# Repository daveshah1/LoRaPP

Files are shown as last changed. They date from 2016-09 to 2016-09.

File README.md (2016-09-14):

# LoRa++

Small, flexible LoRa module designed for HAB use as well as general 
long distance comms.

Features:
 * SX1276 LoRa transceiver
 * Same PCB can be used for 434MHz, 868MHz and probably other 
frequencies (different components required)
 * MMZ09312 PA for >27dBm output power (for 869.525MHz use in EU). 
Optional, can be bypassed with 0 ohm resistors if not needed.
 * SAW filter and MAAL-010704 LNA (also optional) in receive path 

Note: this is still in the fairly early design phase; the PCB design has 
not yet been checked or built.

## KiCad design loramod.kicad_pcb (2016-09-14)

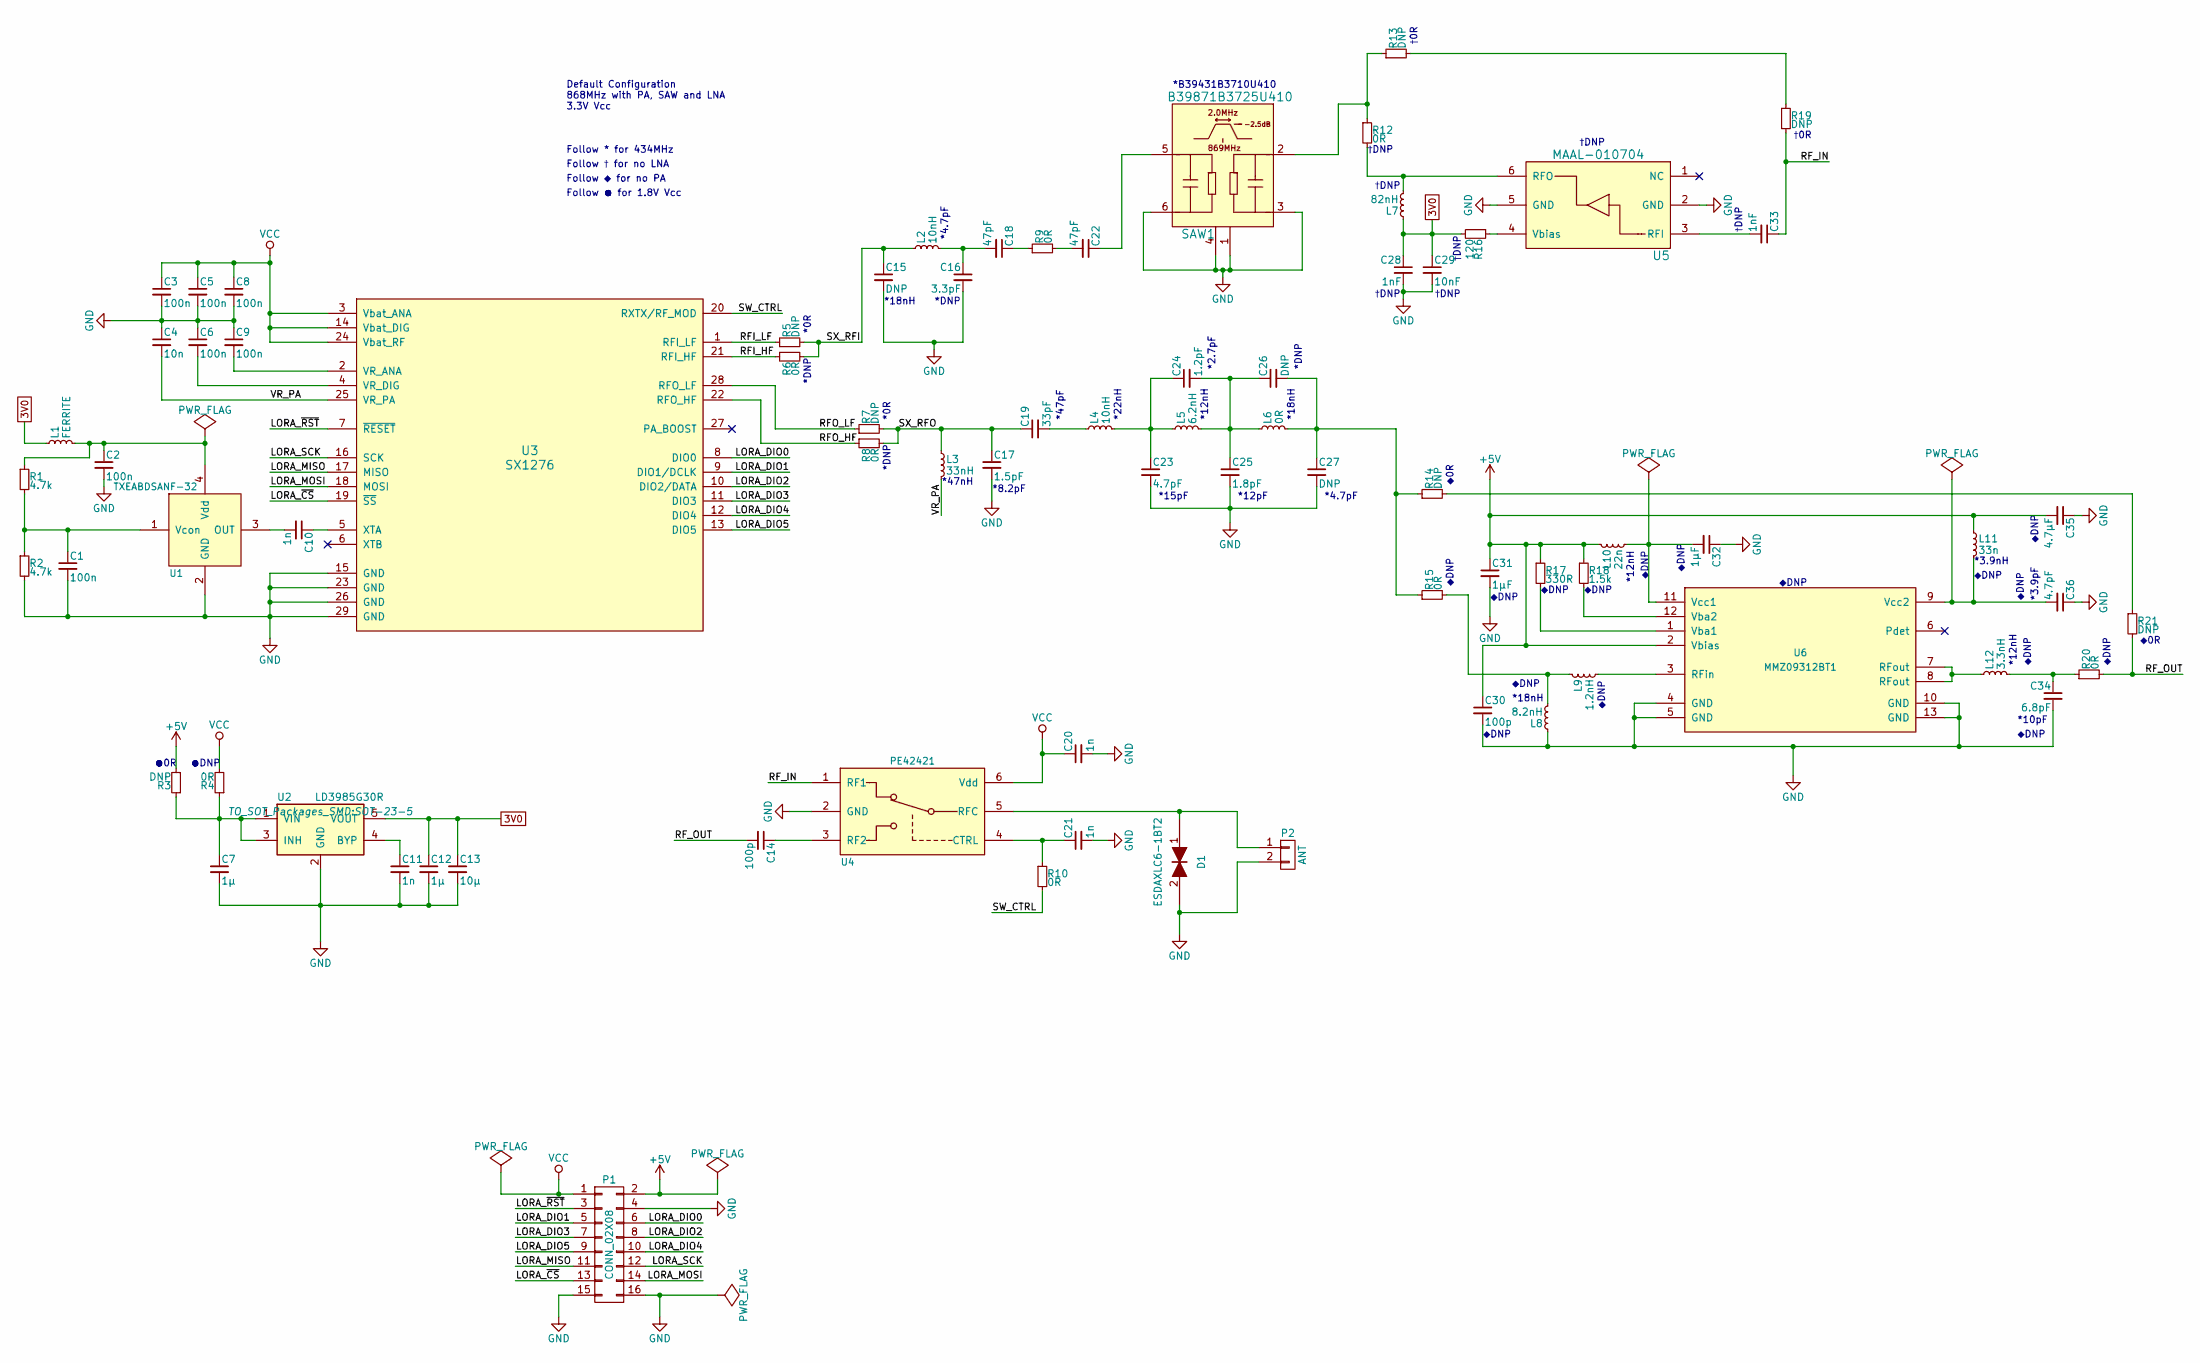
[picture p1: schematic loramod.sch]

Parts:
C1, C2, C3, C5, C6, C8, C9: 100n; C_0402
C4: 10n; C_0402
C7: 1µ; C_0603_HandSoldering
C10, C11, C20, C21: 1n; C_0402
C12: 1µ; C_0603
C13: 10µ; C_0805
C14, C30: 100p; C_0402
C15, C26, C27: DNP; C_0402
C16: 3.3pF; C_0402
C17: 1.5pF; C_0402
C18, C22: 47pF; C_0402
C19: 33pF; C_0402
C23, C36: 4.7pF; C_0402
C24: 1.2pF; C_0402
C25: 1.8pF; C_0402
C28, C33: 1nF; C_0402
C29: 10nF; C_0402
C31, C32: 1µF; C_0402
C34: 6.8pF; C_0402
C35: 4.7µF; C_0805
D1: ESDAXLC6-1BT2; C_0402
L1: FERRITE; R_0402
L2, L4: 10nH; R_0402
L3: 33nH; R_0402
L5: 6.2nH; R_0402
L6: 0R; R_0402
L7: 82nH; R_0402
L8: 8.2nH; R_0402
L9: 1.2nH; R_0402
L10: 22n; R_0402
L11: 33n; R_0402
L12: 3.3nH; R_0402
P1: CONN_02X08; Pin_Header_Straight_2x08_Pitch2.00mm
P2: ANT; RFcon
R1, R2: 4.7k; R_0402
R3, R5, R7, R13, R14, R19, R21: DNP; R_0402
R4, R6, R8, R9, R10, R12, R15, R20: 0R; R_0402
R16: 120; R_0402
R17: 330R; R_0402
R18: 1.5k; R_0402
SAW1: B39871B3725U410; SAW-DCC6C
U1: TXEABDSANF-32; TCXO-WT325
U2: LD3985G30R; SOT-23-5
U3: SX1276; QFN-28-1EP_6x6mm_Pitch0.65mm
U4: PE42421; SC-70-6_Handsoldering
U5: MAAL-010704; SC-70-6_Handsoldering
U6: MMZ09312BT1; QFN-12-1EP_3x3mm_Pitch0.5mm

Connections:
3V0: C12.1, C13.1, C28.1, C29.1, L1.1, L7.1, R16.2, U2.5 (VOUT)
+5V: C30.1, C31.1, C35.2, L10.1, L11.1, P1.2, R3.2, R17.1, R18.1, U6.2 (Vbias)
/LORA_DIO0: P1.6, U3.8 (DIO0)
/LORA_DIO1: P1.5, U3.9 (DIO1/DCLK)
/LORA_DIO2: P1.8, U3.10 (DIO2/DATA)
/LORA_DIO3: P1.7, U3.11 (DIO3)
/LORA_DIO4: P1.10, U3.12 (DIO4)
/LORA_DIO5: P1.9, U3.13 (DIO5)
/LORA_MISO: P1.11, U3.17 (MISO)
/LORA_MOSI: P1.14, U3.18 (MOSI)
/LORA_SCK: P1.12, U3.16 (SCK)
/LORA_~CS: P1.13, U3.19 (~SS)
/LORA_~RST: P1.3, U3.7 (~RESET)
/RFI_HF: R6.1, U3.21 (RFI_HF)
/RFI_LF: R5.1, U3.1 (RFI_LF)
/RFO_HF: R8.1, U3.22 (RFO_HF)
/RFO_LF: R7.1, U3.28 (RFO_LF)
/RF_IN: C33.1, R19.2, U4.1 (RF1)
/RF_OUT: C14.2, R20.2, R21.2
/SW_CTRL: R10.2, U3.20 (RXTX/RF_MOD)
/SX_RFI: C15.1, L2.1, R5.2, R6.2
/SX_RFO: C17.1, C19.1, L3.1, R7.2, R8.2
/VR_PA: C4.2, L3.2, U3.25 (VR_PA)
GND: C1.2, C2.2, C3.2, C4.1, C5.2, C6.1, C7.2, C8.2, C9.1, C11.2, C12.2, C13.2, C15.2, C16.2, C17.2, C20.2, C21.2, C23.2, C25.2, C27.2, C28.2, C29.2, C30.2, C31.2, C32.1, C34.2, C35.1, C36.1, D1.2, L8.1, P1.4, P1.15, P1.16, P2.2, R2.2, SAW1.1 (GND), SAW1.3 (GND), SAW1.4 (GND), SAW1.6 (GND), U1.2 (GND), U2.2 (GND), U3.15 (GND), U3.23 (GND), U3.26 (GND), U3.29 (GND), U4.2 (GND), U5.2 (GND), U5.5 (GND), U6.4 (GND), U6.5 (GND), U6.10 (GND), U6.13 (GND)
unnamed: C1.1, R1.2, R2.1, U1.1 (Vcon)
unnamed: C2.1, L1.2, R1.1, U1.4 (Vdd)
unnamed: C6.2, U3.4 (VR_DIG)
unnamed: C7.1, R3.1, R4.1, U2.1 (VIN), U2.3 (INH)
unnamed: C9.2, U3.2 (VR_ANA)
unnamed: C10.1, U3.5 (XTA)
unnamed: C10.2, U1.3 (OUT)
unnamed: C11.1, U2.4 (BYP)
unnamed: C14.1, U4.3 (RF2)
unnamed: C16.1, C18.2, L2.2
unnamed: C18.1, R9.1
unnamed: C19.2, L4.1
unnamed: C21.1, R10.1, U4.4 (CTRL)
unnamed: C22.1, SAW1.5 (OUT)
unnamed: C22.2, R9.2
unnamed: C23.1, C24.1, L4.2, L5.1
unnamed: C24.2, C25.1, C26.1, L5.2, L6.1
unnamed: C26.2, C27.1, L6.2, R14.1, R15.1
unnamed: C32.2, L10.2, U6.11 (Vcc1)
unnamed: C33.2, U5.3 (RFI)
unnamed: C34.1, L12.2, R20.1
unnamed: C36.2, L11.2, U6.9 (Vcc2)
unnamed: D1.1, P2.1, U4.5 (RFC)
unnamed: L7.2, R12.2, U5.6 (RFO)
unnamed: L8.2, L9.1, R15.2
unnamed: L9.2, U6.3 (RFin)
unnamed: L12.1, U6.7 (RFout), U6.8 (RFout)
unnamed: R12.1, R13.1, SAW1.2 (IN)
unnamed: R13.2, R19.1
unnamed: R14.2, R21.1
unnamed: R16.1, U5.4 (Vbias)
unnamed: R17.2, U6.1 (Vba1)
unnamed: R18.2, U6.12 (Vba2)
VCC: C3.1, C5.1, C8.1, C20.1, P1.1, R4.2, U3.3 (Vbat_ANA), U3.14 (Vbat_DIG), U3.24 (Vbat_RF), U4.6 (Vdd)

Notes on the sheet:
*18nH
*DNP
*4.7pF
*DNP
*0R
*B39431B3710U410
Default Configuration 868MHz with PA, SAW and LNA 3.3V Vcc
Follow * for 434MHz
Follow † for no LNA
†0R
†DNP
*47nH
*8.2pF
*47pF
*22nH
*15pF
*12pF
*12nH
*2.7pF
*10pF
*3.9nH
*3.9pF
◆0R
◆DNP
Follow ◆ for no PA
Follow ● for 1.8V Vcc
●0R
●DNP

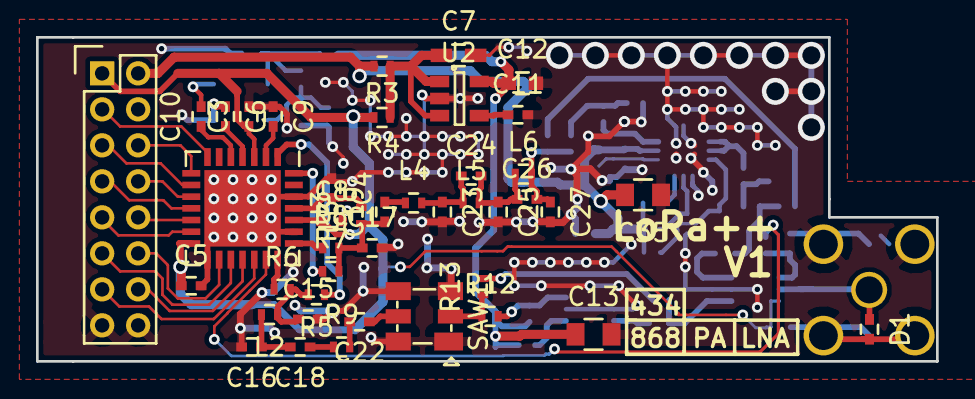
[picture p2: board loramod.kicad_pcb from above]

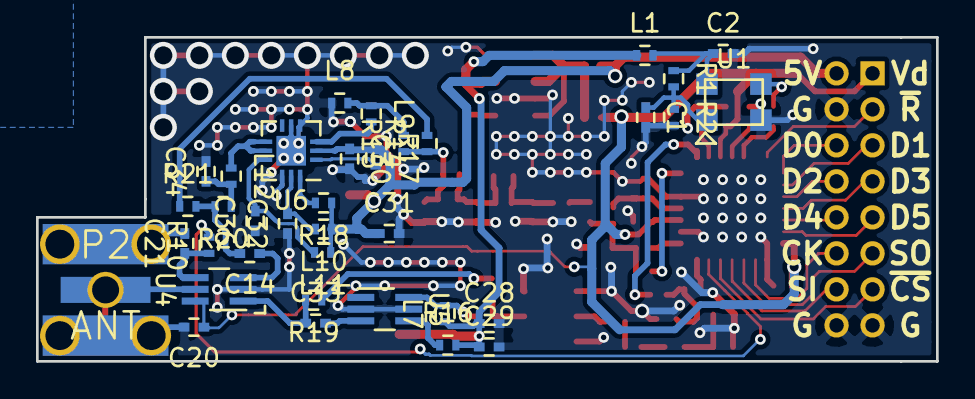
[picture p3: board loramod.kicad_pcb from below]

Board: 4 copper layers, 50.0 x 18.0 mm, 78 parts (36 on the bottom side), 58 nets.

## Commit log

2016-09-14 Initial design with SX1276 and rx path
    [loramod.kicad_pcb, loramod.sch]
2016-09-14 Add PA in Tx path
    [loramod.sch]
2016-09-14 Add RF switch
    [loramod.sch]
2016-09-14 Add IO connector; annotate schematic
    [loramod.sch]
2016-09-14 Start placing PCB parts
    [loramod.kicad_pcb, loramod.sch]
2016-09-14 PCB part placement done
    [loramod.kicad_pcb, loramod.sch]
2016-09-14 All tracks routed, need to create ground planes
    [loramod.kicad_pcb]
2016-09-14 Finish PCB attempt 1; add README
    [loramod.kicad_pcb]
2016-09-14 Modify PCB design to fit with Elecrow's 5cm limit
    [loramod.kicad_pcb]
